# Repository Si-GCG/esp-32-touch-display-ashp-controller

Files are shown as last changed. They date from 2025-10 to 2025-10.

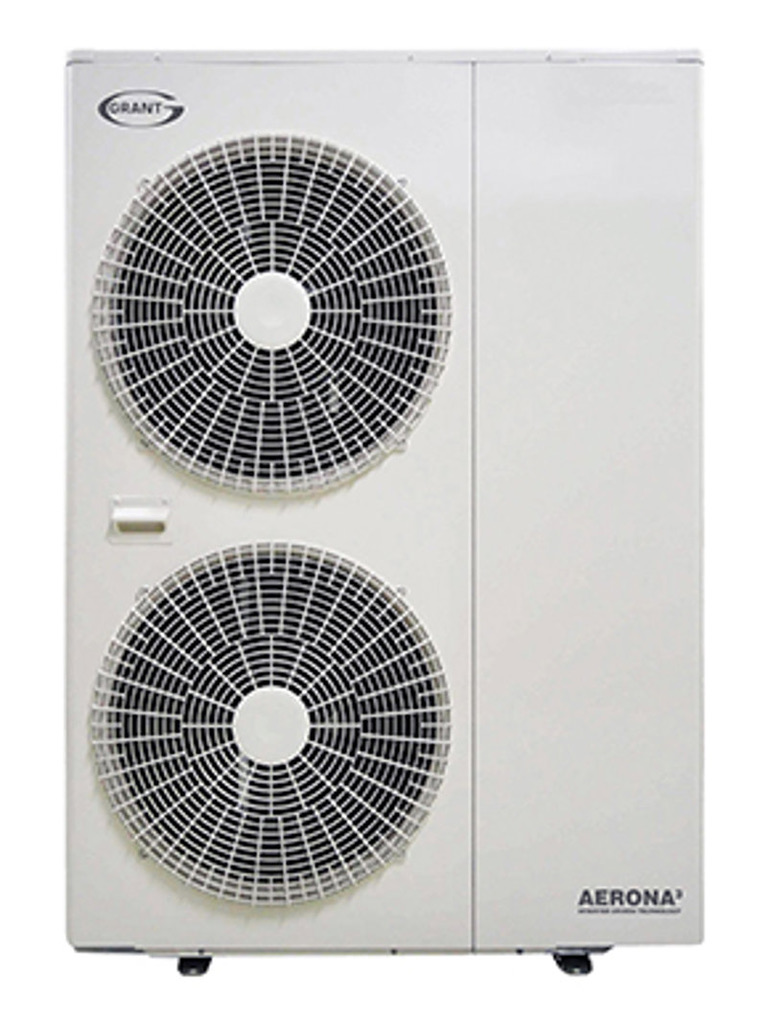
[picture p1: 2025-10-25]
heat-pump-project/images/aerona3.jpeg

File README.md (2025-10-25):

# Grant Aerona3 Touchscreen Controller

A touchscreen controller for the Grant Aerona3 air-source heat pump (ASHP) using a Waveshare ESP32-S3 7" touchscreen display. The device provides local control (touch UI on the display) and remote control via Home Assistant (MQTT or ESPHome integration). This repository contains firmware, UI assets, wiring guidance and Home Assistant integration examples.

Status: WIP — Prototype firmware and documentation.

Table of contents
- Project overview
- Features
- Hardware
  - Recommended parts
  - Power considerations
  - Wiring & pin mapping (example / placeholders)
- Software
  - Architecture & components
  - Build options
  - Configuration (Wi‑Fi, MQTT, ESPHome)
- Home Assistant integration
  - MQTT topics & payloads (Coming soon)
  - Example Home Assistant YAML
- UI design & customization
- Flashing & OTA
- Troubleshooting
- Resources
- Contributing
- License

Project overview
This project replaces or augments a physical controller for the Grant Aerona3 ASHP with a custom touchscreen interface built on a Waveshare ESP32-S3 7" touchscreen display. The device enables:
- Local device control via an on-device touch UI
- Remote monitoring and control from Home Assistant
- Automated schedules and safety interlocks
- Extendable firmware and UI (LVGL or equivalent)

Features
- Full touchscreen UI for weather compensation mode, setpoint and status
- Wi‑Fi connectivity to integrate with Home Assistant
- Remote control via MQTT or ESPHome
- OTA updates (optional)
- Configurable safety limits and error display
- Logging of basic telemetry (temperatures, modes, run status)

Hardware

Recommended parts
- Waveshare ESP32-S3 7-inch capacitive touchscreen display (the ESP32-S3 model)
- Stable 5V power supply USB C
- JST / Dupont wires and appropriate connectors
- Optional enclosure and mounting hardware

Wiring & pin mapping (example / placeholders)
The display typically exposes:
- Display interface (SPI or parallel) — depends on the exact Waveshare model
- Touch controller (I2C or SPI)
- Backlight control (PWM / GPIO)
- Power and ground

Important: consult your exact Waveshare display manual for connector pinouts before wiring. Below is an example mapping pattern — replace with pins for your specific display and board.

Example (replace with actual pins for your hardware):
- 5V VCC (display) -> 5V power supply
- GND (display) -> GND
- SPI SCK (display) -> ESP32-S3 GPIO 18
- SPI MOSI (display) -> ESP32-S3 GPIO 23
- SPI MISO (if used) -> ESP32-S3 GPIO 19
- Reset (display) -> ESP32-S3 GPIO 4
- DC / RS (display) -> ESP32-S3 GPIO 2
- Touch I2C SDA -> ESP32-S3 GPIO 21
- Touch I2C SCL -> ESP32-S3 GPIO 22
- Backlight PWM -> ESP32-S3 GPIO 13

Note: The Waveshare ESP32-S3 model may already integrate the microcontroller and display, changing wiring needs. Use vendor docs.

Software

Architecture & components
- Firmware: ESP32-based firmware using:
  - UI: LVGL (recommended) or a lightweight custom renderer
  - SDL: allows you to quickly iterate using UI changes without having to flash the actual device. Navigate your terminal to the folder with your sdl_test.yaml file and make changes to that file then save then run the following command - esphome run sdl_yaml 
  - Connectivity: Wi‑Fi + MQTT client OR ESPHome
  - Control logic: local state machine to handle modes, setpoints, safety and remote commands
- Home Assistant: configure entities (climate, switches, sensors) using MQTT or ESPHome integration

Build instructions

1. ESPHome
   Edit the secrets.yaml to include your systems details
   Once you are happy with your build run the following commands from your project directory (where your ASHP_ESP32-S3_display.yaml and secrets.yaml files are)
   
   ```
   esphome compile ASHP_ESP32-S3_display.yaml
   esphome run ASHP_ESP32-S3_display.yaml
   ```

Configuration (Wi‑Fi, MQTT, ESPHome) (I am still working on MQTT)
- Wi‑Fi: SSID and password stored in secure config (ideally prompt on first boot or use provisioning).
- MQTT: Broker address, username, password, base topic
- ESPHome: If using ESPHome, implement display and custom components through its YAML.

Home Assistant integration

MQTT topics & payloads (example)
- Base topic: grant/aerona3
- Commands:
  - grant/aerona3/command/set_mode -> payload: "heat" | "cool" | "off" | "auto"
  - grant/aerona3/command/set_temperature -> payload: "21.5" (numeric)
  - grant/aerona3/command/set_fan -> payload: "low" | "medium" | "high" | "auto"
  - grant/aerona3/command/power -> payload: "on" | "off"
- State / telemetry:
  - grant/aerona3/state/mode -> "heat"
  - grant/aerona3/state/temperature -> "21.2"
  - grant/aerona3/state/target -> "22.0"
  - grant/aerona3/state/fan -> "auto"
  - grant/aerona3/state/error -> "E01" or empty string

Example Home Assistant (MQTT) configuration
Replace broker / credentials / topics as needed.

configuration.yaml example (MQTT Climate)
```yaml
climate:
  - platform: mqtt
    name: "Grant Aerona3"
    mode_command_topic: "grant/aerona3/command/set_mode"
    mode_state_topic: "grant/aerona3/state/mode"
    modes:
      - "off"
      - "heat"
      - "cool"
      - "auto"
    temperature_command_topic: "grant/aerona3/command/set_temperature"
    current_temperature_topic: "grant/aerona3/state/temperature"
    temperature_state_topic: "grant/aerona3/state/target"
    min_temp: 5
    max_temp: 30
    temp_step: 0.5
```

You can also expose binary switches (power) with MQTT switch entities.

ESPHome example
- ESPHome can simplify the HA side (native integration), but complex LVGL GUIs will likely need custom code outside ESPHome. Use ESPHome if you prefer configuration-by-YAML and built-in OTA + HA discovery.

UI design & customization
- The UI is implemented using LVGL (recommended) or a chosen GUI framework.
- Suggested screens:
  - Home: current mode, indoor temp, setpoint, quick controls (power, mode)
  - Settings: Wi‑Fi, MQTT (coming soon)
  - Diagnostics: logs, error codes, firmware version
- Assets: icons, fonts and translations are stored in /assets (TBD)
- The UI is modular — customize layouts, color themes, and widgets.

Flashing & OTA

Initial flashing (USB)
- Connect the ESP32-S3 via USB
- Use PlatformIO or esptool to upload the firmware binary

OTA updates
- Implement OTA (ArduinoOTA, ESP-IDF OTA or custom) to allow firmware updates over Wi‑Fi
- Secure OTA with authentication if exposed to untrusted networks

Troubleshooting
- Display not showing: check power, backlight, and wiring. Verify contrast/power pins and that the display uses the expected interface (SPI vs parallel).
- Touch not responding: check touch controller interface (I2C vs SPI) and calibrate.
- Wi‑Fi connection issues: verify credentials, AP signal, and power stability.
- MQTT messages not received: check broker settings, topic names and credentials. Use mosquitto_sub or MQTT Explorer to debug.
- Heat pump control: ensure any wiring to the heat pump is done only per the vendor's instructions and local safety codes. Use optoisolators or proper relays when switching mains.

Resuorces
https://github.com/espressif/esp-bsp/tree/master/components/lcd_touch/esp_lcd_touch_gt911

https://www.waveshare.com/wiki/ESP32-S3-Touch-LCD-7

https://docs.lvgl.io/8.3/examples.html#

Safety & regulatory notes
- This project interfaces with HVAC equipment. Incorrect wiring or software bugs can cause equipment damage or unsafe operation.
- If you're not confident with electrical work, consult a qualified HVAC/electrical technician.
- Never bypass built-in safety systems on the ASHP.

Contributing
- Open an issue for feature requests or bugs
- Fork, make changes in a feature branch, test, and open a pull request
- Follow code style in the repo and include tests where appropriate
- Please document any hardware-specific pinouts and wiring you test

Repository structure (suggested)
- /includes — add any modbus registers dependent on type (Sensors, Switches , Binary Sensors, Input Numbers etc)
- /fonts— hardware diagrams, vendor datasheets, pinouts
- /images — any images you want to include in your display

What I have included
- A complete README template covering project goals, components, guidance for building, wiring, and Home Assistant integration with sample MQTT topics and Home Assistant YAML.

License
This repository defaults to the GPL 2.0 license. 

Acknowledgements
- Waveshare for the hardware
- LVGL community for GUI components
- Home Assistant community for integration patterns
- Benny Diamond and his awesome project - https://github.com/bennydiamond/esphome_lvgl_hmi_garage

Contact / author
- Si-GCG (project owner)

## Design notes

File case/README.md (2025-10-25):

Printable design file has been modified from the [original design](https://www.thingiverse.com/thing:6701545) to remove the cut-out hole at the bottom. You will need to make your own hole to pass wires through.
The no hole version is from https://github.com/bennydiamond/esphome_lvgl_hmi_garage Huge thanks to Benny Diamond for giving me a greeat start point with this project.

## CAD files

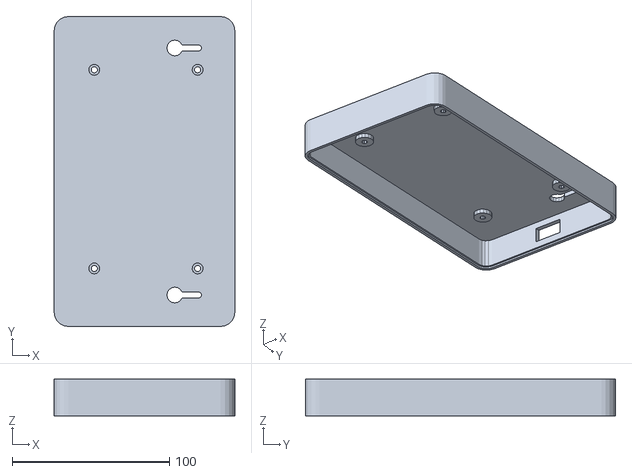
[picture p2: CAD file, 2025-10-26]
case/esp32-s3-touch-lcd-7-case_right_side_hole.stl
114.8 x 196.9 x 23.5

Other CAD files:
case/esp32-s3-touch-lcd-7-case_left_side_hole.stl
case/esp32-s3-touch-lcd-7-case.stp
case/esp32-s3-touch-lcd-7-case_bottom_hole.stl
case/esp32-s3-touch-lcd-7-case_nohole.stl

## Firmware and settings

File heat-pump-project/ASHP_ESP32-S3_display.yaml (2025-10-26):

esphome:
  name: ashp-display
  friendly_name: "ASHP Display"
  min_version: 2025.05.2
  platformio_options:
    build_unflags: -Werror=all
    board_build.flash_mode: dio
    build_flags:
      - -DBOARD_HAS_PSRAM
    board_build.esp-idf.memory_type: qio_opi
    board_upload.maximum_ram_size: 524288
    board_build.flash_size: 8MB
  on_boot:
    priority: -100  # Run after everything else is initialized
    then:
      - script.execute: wake_backlight
esp32:
  board: esp32-s3-devkitc-1
  variant: esp32s3
  flash_size: 8MB
  cpu_frequency: 240MHz
  framework:
    type: esp-idf
    sdkconfig_options:
      CONFIG_ESP32S3_DATA_CACHE_64KB: "y"
      CONFIG_ESPTOOLPY_FLASHSIZE_8MB: "y"
      CONFIG_FREERTOS_HZ: "1000"
      CONFIG_ESP_DEFAULT_CPU_FREQ_MHZ_240: y
      CONFIG_ESPTOOLPY_FLASHMODE_QIO: y
      CONFIG_ESPTOOLPY_FLASHFREQ_80M: y
      CONFIG_SPIRAM_MODE_OCT: y
      CONFIG_IDF_EXPERIMENTAL_FEATURES: y
      CONFIG_SPIRAM_SPEED_80M: y
      CONFIG_SPIRAM_FETCH_INSTRUCTIONS: y
      CONFIG_SPIRAM_RODATA: y
      CONFIG_ESP32S3_DATA_CACHE_LINE_64B: y
    advanced:
      enable_idf_experimental_features: False

# host:
#   mac_address: "de:ad:be:ef:fe:ed"

logger:
  level: DEBUG
  hardware_uart: UART0
  baud_rate: 0
  logs:
    safe_mode: INFO
    debug: INFO
    main: INFO
    esp-idf: WARN
    esp32.preferences: INFO
    wifi: WARN
    api: WARN
    sntp: WARN
    i2c: WARN
    i2c.idf: WARN
    ch422g: WARN
    touchscreen: WARN
    gt911.touchscreen: WARN
    switch: WARN
    sensor: WARN
    binary_sensor: WARN
    text_sensor: WARN
    light: WARN
    select: WARN
    homeassistant.sensor: WARN
    homeassistant.binary_sensor: WARN
    homeassistant.text_sensor: WARN
    template.switch: WARN
    script: WARN
    http_request: WARN
    http_request.idf: WARN
    online_image: WARN
    number: WARN

wifi:
  ssid: !secret wifi_ssid
  password: !secret wifi_password

http_request:
  verify_ssl: false

debug:

api:
  encryption:
    key: !secret api_encryption_key

ota:
  - platform: esphome
    password: !secret ota_password

psram:
  mode: octal
  speed: 80MHz

ch422g:
  - id: io_ex

i2c:
  sda: 8
  scl: 9
  frequency: 400kHz
  scan: false
  id: bus_a

light:
  - platform: binary
    name: "Display Backlight"
    id: display_backlight
    output: backlight_gpio
    restore_mode: ALWAYS_ON

globals:
  - id: backlight_active
    type: bool
    restore_value: no
    initial_value: 'true'

script:
  - id: backlight_timeout
    then:
      - if:
          condition:
            lambda: 'return id(backlight_active);'
          then:
            - lambda: |-
                ESP_LOGI("backlight", "Display timeout - turning off backlight");
                id(backlight_active) = false;
            - light.turn_off: display_backlight

  - id: wake_backlight
    mode: restart  # Restart if already running (resets timer)
    then:
      # Turn on backlight if it was off
      - if:
          condition:
            lambda: 'return !id(backlight_active);'
          then:
            - lambda: |-
                ESP_LOGI("backlight", "Waking display from touch");
                id(backlight_active) = true;
            - light.turn_on: display_backlight
      
      # Wait 5 minutes, then timeout
      - delay: 300s
      - script.execute: backlight_timeout


safe_mode:

button:
  - platform: safe_mode
    name: "Device Restart (Safe mode)"
    id: id_button_device_restart_safe_mode
    icon: mdi:restart-alert

output:
  - platform: gpio
    id: backlight_gpio
    pin:
      ch422g: io_ex
      number: 0
      mode: output
      inverted: false

# Touchscreen (hardware)
touchscreen:
  platform: gt911
  address: 0x5D
  id: my_touchscreen
  interrupt_pin: 4
  reset_pin:
    ch422g: io_ex
    number: 1
  on_touch:
    - script.execute: wake_backlight
# Display (hardware)
display:
  - platform: rpi_dpi_rgb
    id: device_display
    update_interval: never
    auto_clear_enabled: false
    color_order: RGB
    pclk_frequency: 21MHz
    dimensions:
      width: 800
      height: 480
    reset_pin:
      ch422g: io_ex
      number: 2
    de_pin:
      number: 5
    hsync_pin:
      number: 46
      ignore_strapping_warning: true
    vsync_pin:
      number: 3
      ignore_strapping_warning: true
    pclk_pin: 7
    pclk_inverted: true
    hsync_back_porch: 16
    hsync_front_porch: 210
    hsync_pulse_width: 4
    vsync_back_porch: 13
    vsync_front_porch: 4
    vsync_pulse_width: 4
    data_pins:
      red: [1, 2, 42, 41, 40]
      blue: [14, 38, 18, 17, 10]
      green: [39, 0, 45, 48, 47, 21]

# UART/Modbus (hardware—keep wiring as per your device)
uart:
  id: mod_bus
  tx_pin: GPIO15
  rx_pin: GPIO16
  baud_rate: 19200
  stop_bits: 1
  parity: NONE
  data_bits: 8

modbus:
  id: modbus1
  uart_id: mod_bus

modbus_controller:
  id: aerona3
  address: 1
  modbus_id: modbus1
  update_interval: 10s
  command_throttle: 200ms
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

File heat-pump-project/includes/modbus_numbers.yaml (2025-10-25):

- platform: modbus_controller
  modbus_controller_id: aerona3
  name: "Set Fixed Flow Temperature"
  id: set_fixed_flow_temp
  register_type: holding
  address: 2
  unit_of_measurement: "°C"
  device_class: temperature
  min_value: 20
  max_value: 60
  step: 0.5
  multiply: 10
  mode: box
  icon: "mdi:thermometer"

# Set Max Flow Temperature → Max dial
- platform: modbus_controller
  modbus_controller_id: aerona3
  name: "Set Max Flow Temperature"
  id: set_max_flow_temp
  register_type: holding
  address: 3
  unit_of_measurement: "°C"
  device_class: temperature
  min_value: 25
  max_value: 65
  step: 0.5
  multiply: 10  # write scaling
  mode: box
  icon: "mdi:thermometer-chevron-up"
  on_value:
    - lvgl.arc.update:
        id: max_temp_dial
        value: !lambda |-
          // x is already °C from ESPHome (read side); clamp to dial min/max
          float v = x;
          if (v < 20) v = 20;
          if (v > 65) v = 65;
          return v;
    - lvgl.label.update:
        id: max_temp_dial_label
        text:
          format: "%.0f°C"
          args: [ 'x' ]

- platform: modbus_controller
  modbus_controller_id: aerona3
  name: "Set Min Flow Temperature"
  id: set_min_flow_temp
  register_type: holding
  address: 4
  unit_of_measurement: "°C"
  device_class: temperature
  min_value: 15
  max_value: 40
  step: 0.5
  multiply: 10
  mode: box
  icon: "mdi:thermometer-chevron-down"
  on_value:
    - lvgl.arc.update:
        id: min_temp_dial
        value: !lambda |-
          float v = x;
          if (v < 20) v = 20;   // keep dial’s visual min consistent (your dial min is 20)
          if (v > 65) v = 65;   // dial max is 65
          return v;
    - lvgl.label.update:
        id: min_temp_dial_label
        text:
          format: "%.0f°C"
          args: [ 'x' ]

- platform: modbus_controller
  modbus_controller_id: aerona3
  name: "Set Min Outdoor Air Temperature"
  register_type: holding
  address: 5
  unit_of_measurement: "°C"
  device_class: temperature
  min_value: -20
  max_value: 10
  step: 0.5
  multiply: 10
  mode: box
  icon: "mdi:thermometer-minus"

- platform: modbus_controller
  modbus_controller_id: aerona3
  name: "Set Max Outdoor Air Temperature"
  register_type: holding
  address: 6
  unit_of_measurement: "°C"
  device_class: temperature
  min_value: 10
  max_value: 35
  step: 0.5
  multiply: 10
  mode: box
  icon: "mdi:thermometer-plus"

# Zone 2 Settings
- platform: modbus_controller
  modbus_controller_id: aerona3
  name: "Set Fixed Flow Temperature Zone 2"
  register_type: holding
  address: 7
  unit_of_measurement: "°C"
  device_class: temperature
  min_value: 20
  max_value: 60
  step: 0.5
  multiply: 10
  mode: box
  icon: "mdi:thermometer"

- platform: modbus_controller
  modbus_controller_id: aerona3
  name: "Set Max Flow Temperature Zone 2"
  register_type: holding
  address: 8
  unit_of_measurement: "°C"
  device_class: temperature
  min_value: 25
  max_value: 65
  step: 0.5
  multiply: 10
  mode: box
  icon: "mdi:thermometer-chevron-up"

- platform: modbus_controller
  modbus_controller_id: aerona3
  name: "Set Min Flow Temperature Zone 2"
  register_type: holding
  address: 9
  unit_of_measurement: "°C"
  device_class: temperature
  min_value: 15
  max_value: 40
  step: 0.5
  multiply: 10
  mode: box
  icon: "mdi:thermometer-chevron-down"

- platform: modbus_controller
  modbus_controller_id: aerona3
  name: "Set Min Outdoor Air Temperature Zone 2"
  register_type: holding
  address: 10
  unit_of_measurement: "°C"
  device_class: temperature
  min_value: -20
  max_value: 10
  step: 0.5
  multiply: 10
  mode: box
  icon: "mdi:thermometer-minus"

- platform: modbus_controller
  modbus_controller_id: aerona3
  name: "Set Max Outdoor Air Temperature Zone 2"
  register_type: holding
  address: 11
  unit_of_measurement: "°C"
  device_class: temperature
  min_value: 10
  max_value: 35
  step: 0.5
  multiply: 10
  mode: box
  icon: "mdi:thermometer-plus"

# Hysteresis Settings
- platform: modbus_controller
  modbus_controller_id: aerona3
  name: "Set Hysteresis Water Setpoint"
  register_type: holding
  address: 21
  unit_of_measurement: "°C"
  device_class: temperature
  min_value: 1
  max_value: 10
  step: 0.5
  multiply: 10
  mode: box
  icon: "mdi:delta"

# DHW Settings
- platform: modbus_controller
  modbus_controller_id: aerona3
  name: "Set DHW Comfort Temperature"
  register_type: holding
  address: 28
  unit_of_measurement: "°C"
  device_class: temperature
  min_value: 40
  max_value: 65
  step: 0.5
  multiply: 10
  mode: box
  icon: "mdi:water-thermometer"

- platform: modbus_controller
  modbus_controller_id: aerona3
  name: "Set DHW Economy Temperature"
  register_type: holding
  address: 29
  unit_of_measurement: "°C"
  device_class: temperature
  min_value: 35
  max_value: 60
  step: 0.5
  multiply: 10
  mode: box
  icon: "mdi:water-thermometer-outline"
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

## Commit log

2025-10-25 Refactor SDL test configuration for LVGL widgets
    Removed old LVGL theme definitions and added new widgets for compressor frequency and temperature settings.
2025-10-25 Update README with additional resources section
    Added resources for ESP32-S3 Touch LCD and LVGL examples.
2025-10-26 Implement backlight control and UI updates
    Added backlight control and display timeout functionality. Updated UI elements for temperature and flow controls.
